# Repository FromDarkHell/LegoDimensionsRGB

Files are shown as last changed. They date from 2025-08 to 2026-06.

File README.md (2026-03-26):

## LegoDimensionsRGB

This project is a reverse-engineered implementation of a LEGO Dimensions (currently *only* PS3 / Wii U) playpad.  
This project also includes a simpler project which communicates with an OEM playpad to act as a lamp/night-light, as well as a Python script for communication as well.

### Project Layout
Inside of `projects`, you can see a few different sub-projects which each have their own purpose.

- [basic-emulator](/projects/basic-emulator/) is an implementation of the playpad HID spec, running on a Raspberry Pi Pico W, alongside a Web UI for easy controls.
- [rgb-controller](/projects/rgb-controller/) is a simpler project which sends basic USB HID commands *to* an existing, stock playpad for use as a lamp. This is powered by an ESP32-S3, and comes with a simple Web UI for controlling colors.

### Credits

A large portion of the emulator project is based on [AlinaNova21/node-ld](https://github.com/AlinaNova21/node-ld/tree/master), as well as [Berny23/LD-Toypad-Emulator](https://github.com/Berny23/LD-ToyPad-Emulator).

The Python tools is predominantly based on [woodenphone/lego_dimensions_protocol](https://github.com/woodenphone/lego_dimensions_protocol/blob/master/lego_dimensions_gateway.py). The main difference is that I have updated it to support Python 3 as well as added a `connected()` status function to determine if the playpad was disconnected.

### Support

If you for some reason want to support me financially for this project (or others I make), you can donate to me via [ko-fi](https://ko-fi.com/fromdarkhell) or [Patreon](https://patreon.com/fromdarkhell).



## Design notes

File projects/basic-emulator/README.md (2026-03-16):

# `basic-emulator`

A hardware/firmware project that emulates a LEGO Dimensions Toypad using a Raspberry Pi Pico W (or Pico 2W). It presents itself to a host console as a genuine playpad, and exposes a web interface for managing toys, placing them on the pad, etc.

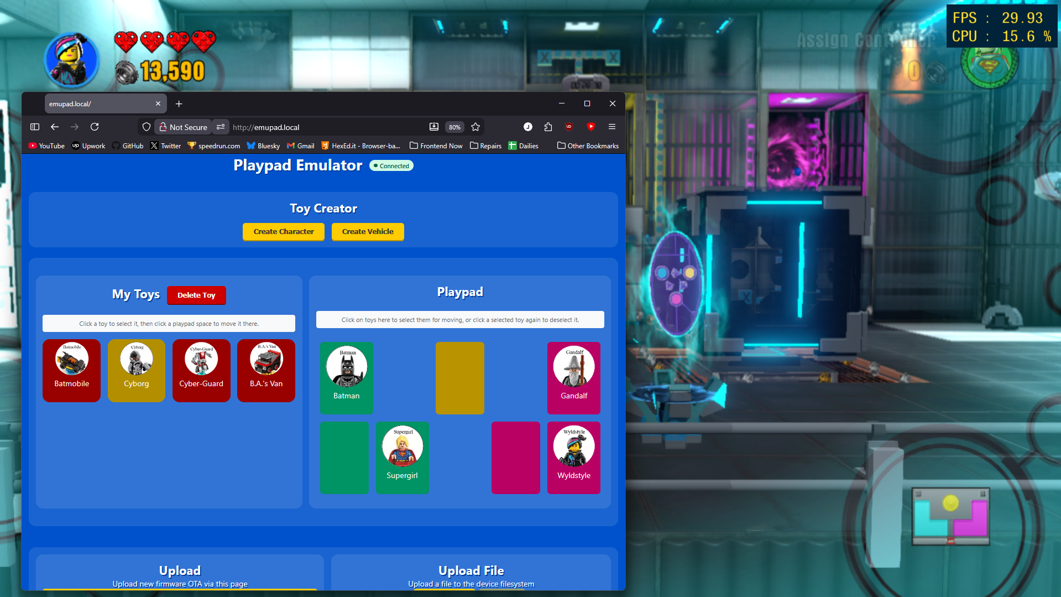
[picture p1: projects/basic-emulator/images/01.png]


---

## Firmware

The firmware lives in `firmware/` and is built with **PlatformIO**.

### Prerequisites

- [PlatformIO Core](https://docs.platformio.org/en/latest/core/installation/index.html) (CLI or IDE)
- A Raspberry Pi Pico W **or** Pico 2W
- A USB cable

### Building & Flashing

```bash
# Clone / enter the firmware directory
cd firmware

# Build for your target platform: `picow` or `pico2w`
pio run -e pico2w

# Flash (put the board in BOOTSEL mode first, then)
pio run -e picow --target upload
```

The project uses the `earlephilhower` Arduino core for RP2040/RP2350 and the `LittleFS` filesystem. Key library dependencies (resolved automatically by PlatformIO) are:

- `ESPAsyncWebServer` - async HTTP server
- `ElegantOTA` - over-the-air firmware updates
- `ArduinoJson` - JSON serialization
- `Adafruit TinyUSB Library` - USB HID stack

### Uploading the Filesystem Image

The web interface (`data/`) must be uploaded to the Pico's LittleFS partition separately:

```bash
pio run -e picow --target uploadfs
```

This packages tag images, etc into a LittleFS image and writes it to the device.

---

## First-Time Setup

On first boot (or after a factory reset), the device has no Wi-Fi credentials and enters **captive-portal mode**:

1. The LED on the board blinks 5 times rapidly to indicate portal mode.
2. A Wi-Fi access point named `captive` appears. Connect to it from your phone or computer.
3. Your device should automatically redirect to the setup page. If it doesn't, navigate to `http://192.168.4.1`.
4. Enter your Wi-Fi **SSID** (Name) and **Password**, then tap **Connect**.
5. The device saves the credentials, reboots, and connects to your network.

After a successful connection, the device should be accessible at:

```
http://emupad.local
```
---

## Using the Web Interface

The main page at `http://emupad.local` is divided into three areas: **Toy Creator**, **My Toys / Playpad**, and an **Advanced** section.

### Toy Creator

Click **Create Character** or **Create Vehicle** to open a selector modal populated from the built-in JSON databases (`json/characters.json` and `json/vehicles.json`). These contain every released LEGO Dimensions character and vehicle along with their IDs and abilities.

- For **characters**, click the character's portrait to add it to your toybox.
- For **vehicles**, expand the entry to see the base form and any rebuild variants, then click the one you want.

Each toy is assigned a random NFC UID at creation time so the game treats it as a unique physical tag.

### Playpad

The on-screen playpad mirrors the physical layout of the real LEGO Dimensions toypad:

```
[ Left  ]       [ Center ]       [ Right ]
[ Left  ][ Left ]         [ Right ][ Right ]
```

**Moving a toy onto the pad:**
1. Click a toy in the **My Toys** list - it highlights with a blue dashed border.
2. Click any empty pad space. The toy moves there and the host console is notified via a USB HID event.

**Moving a toy between pad spaces:**
1. Click a toy already on the pad to select it.
2. Click another pad space (occupied or empty). The toys swap.

**Moving a toy back to the toybox:**
- Click a selected toy on the pad a second time, or click **Delete Toy** while a toybox toy is selected to permanently remove it.

The pad color/flash/fade animations shown in the UI are driven by a **WebSocket** connection (`ws://emupad.local/ws`) that mirrors the real LED state pushed by the game.

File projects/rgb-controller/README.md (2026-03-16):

## rgb-controller

This project is a simple ESP32-S3-based controller for (PS3/Wii U/PS4) LEGO Dimensions playpads.  
Note: **This project does not emulate a full playpad. It only provides remote control of the LED colors via a web interface.**

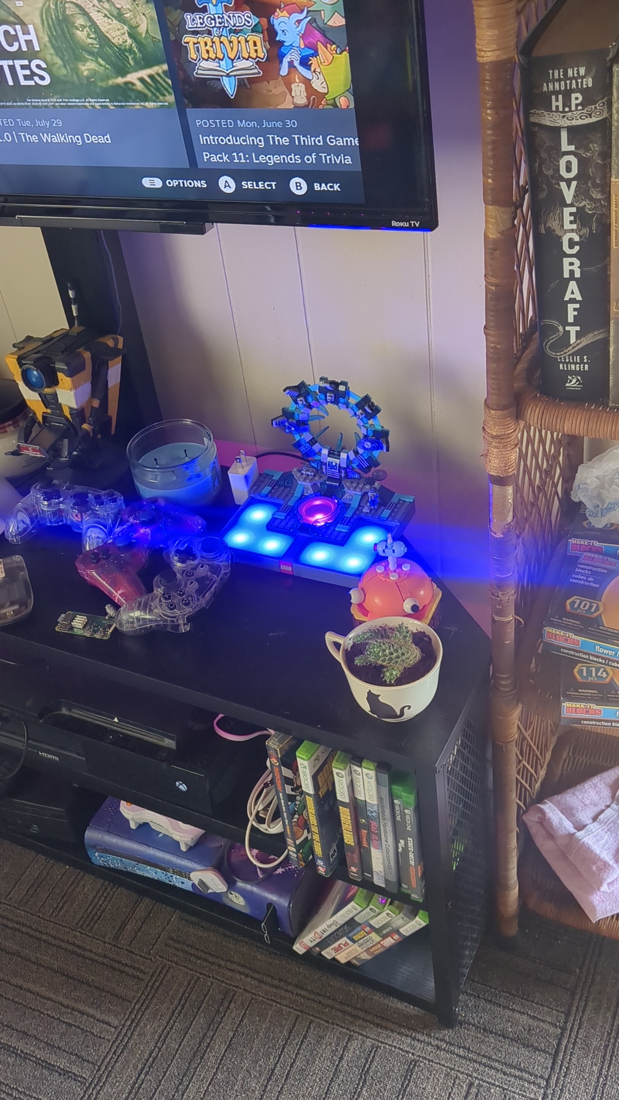
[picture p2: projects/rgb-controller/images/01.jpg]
  
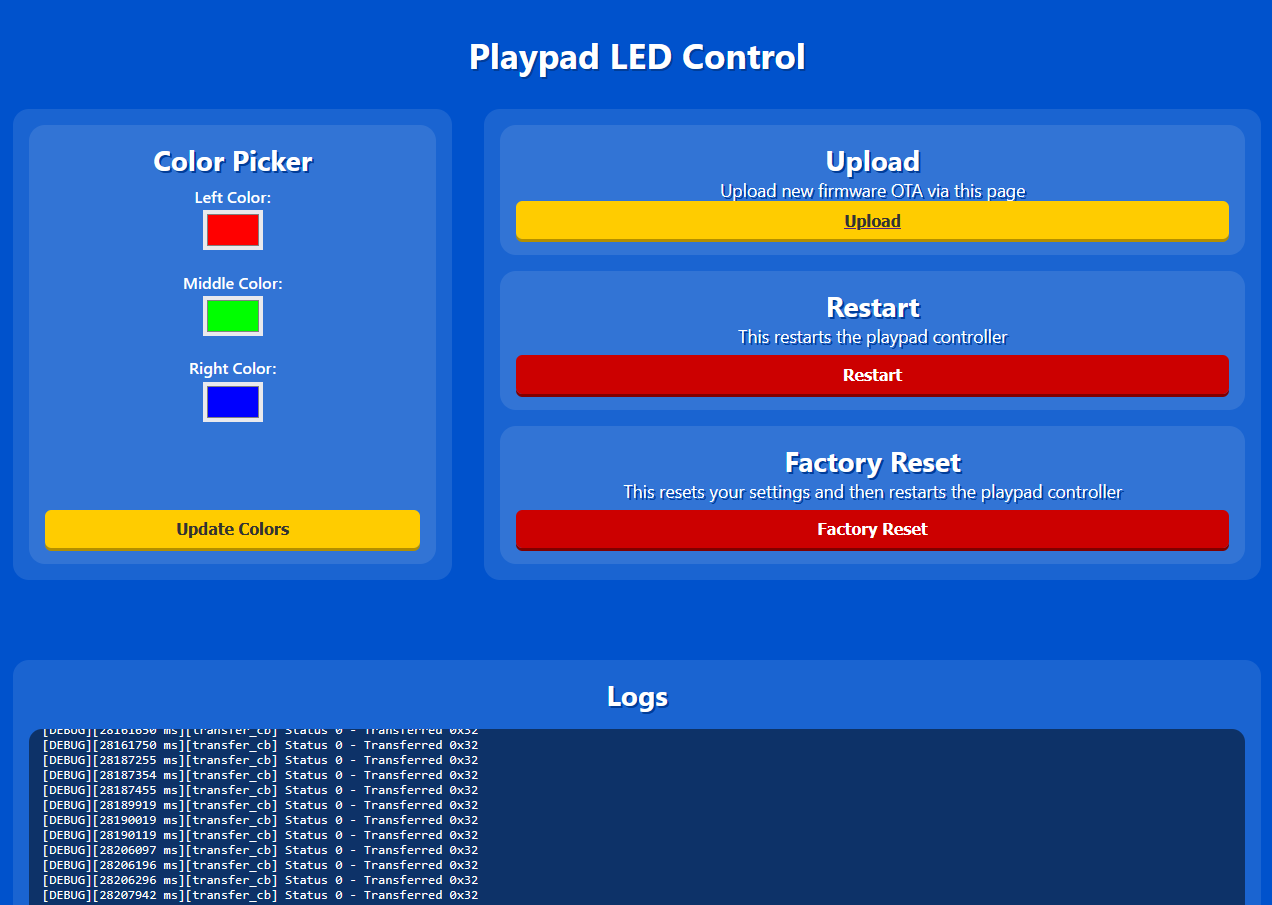
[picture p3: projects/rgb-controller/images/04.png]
  

### Features

- Control the colors via a basic HTML webpage
- (Semi) real-time HTTP logs of USB packets / etc

### Hardware
- ESP32-S3 (i.e. [Seeed Studio XIAO ESP32-S3](https://wiki.seeedstudio.com/xiao_esp32s3_getting_started/))
- USB 2.0 Breakout Board ([Example](https://www.amazon.com/dp/B07W7XMV3W))

How To:
- Connect the USB breakout board D-/D+ pins to your ESP32  
- Splice a USB cable (or use a USB C/etc breakout board), and connect the VUSB and GND to the ESP32 *and* the USB Breakout Board.  

Additionally, this repo also includes a basic schematic & PCB which you can use as a guide, or as an easy to use wiring setup. Enjoy!  

### Usage

1. Flash the firmware onto your ESP32-S3
2. Wire your ESP32-S3 (see above)
3. Connect your ESP32-S3 to your power source
4. It will create a WiFi AP you can connect to named, `captive`.
    - Connect to `captive`, and then enter your WiFi credentials.
5. Wait for the reboot, and connect to your WiFi network.
6. Then you can access the playpad via `playpad.local` (via MDNS)
7. Start changing colors!

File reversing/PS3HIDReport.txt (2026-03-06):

    =========================== USB Port20 ===========================

Connection Status        : 0x01 (Device is connected)
Port Chain               : 4-20
Properties               : 0x00
 IsUserConnectable       : no
 PortIsDebugCapable      : no
 PortHasMultiCompanions  : no
 PortConnectorIsTypeC    : no
ConnectionIndex          : 0x14 (Port 20)

      ========================== Summary =========================
Vendor ID                : 0x0E6F (Performance Designed Products, LLC)
Product ID               : 0x0241
Manufacturer String      : "PDP LIMITED. "
Product String           : "LEGO READER V2.10"
Serial                   : "P.D.P.000000"
USB Version              : 2.0 (but 12 Mbit/s FullSpeed only)
Port maximum Speed       : High-Speed
Device maximum Speed     : Full-Speed
Device Connection Speed  : Full-Speed
Self powered             : no
Demanded Current         : 500 mA
Used Endpoints           : 3

      ======================== USB Device ========================

        +++++++++++++++++ Device Information ++++++++++++++++++
Device Description       : LEGO READER V2.10
Device Path 1            : \\?\USB#VID_0E6F&PID_0241#P.D.P.000000#{a5dcbf10-6530-11d2-901f-00c04fb951ed} (GUID_DEVINTERFACE_USB_DEVICE)
Device Path 2            : \\?\USB#VID_0E6F&PID_0241#P.D.P.000000#{f9918b60-abfb-433d-b843-7d22a140b576}
Kernel Name              : \Device\USBPDO-21
Device ID                : USB\VID_0E6F&PID_0241\P.D.P.000000
Hardware IDs             : USB\VID_0E6F&PID_0241&REV_0100 USB\VID_0E6F&PID_0241
Driver KeyName           : {eb781aaf-9c70-4523-a5df-642a87eca567}\0001
Driver                   : \SystemRoot\system32\DRIVERS\libusb0.sys (Version: 1.4.0.0  Date: 2025-06-22  Company: https://github.com/mcuee/libusb-win32)
Driver Inf               : C:\WINDOWS\inf\oem47.inf
Legacy BusType           : PNPBus
Class                    : libusb-win32 devices
Class GUID               : {eb781aaf-9c70-4523-a5df-642a87eca567}
Service                  : libusb0
Enumerator               : USB
Location Info            : Port_#0020.Hub_#0001
Address                  : 20
Location IDs             : PCIROOT(0)#PCI(0103)#PCI(0000)#USBROOT(0)#USB(20), ACPI(_SB_)#ACPI(PCI0)#ACPI(GPP2)#ACPI(PTXH)#ACPI(RHUB)#ACPI(PO20)
Container ID             : {c89eb567-36c5-5252-9b41-de3970082e29}
Manufacturer Info        : Logic3
Capabilities             : 0x94 (Removable, UniqueID, SurpriseRemovalOK)
Status                   : 0x0180600A (DN_DRIVER_LOADED, DN_STARTED, DN_DISABLEABLE, DN_REMOVABLE, DN_NT_ENUMERATOR, DN_NT_DRIVER)
First Install Date       : 2026-02-15 16:47:03
Last Arrival Date        : 2026-02-15 17:16:39
EnhancedPowerMgmtEnabled : 0
Power State              : D0 (supported: D0, D3, wake from D0)

        +++++++++++++++++ Registry USB Flags +++++++++++++++++
HKEY_LOCAL_MACHINE\SYSTEM\CurrentControlSet\Control\usbflags\0E6F02410100
 osvc                    : REG_BINARY 00 00

        ---------------- Connection Information ---------------
Connection Index         : 0x14 (Port 20)
Connection Status        : 0x01 (DeviceConnected)
Current Config Value     : 0x01 (Configuration 1)
Device Address           : 0x5F (95)
Is Hub                   : 0x00 (no)
Device Bus Speed         : 0x01 (Full-Speed)
Number of open Pipes     : 0x02 (2 pipes to data endpoints)
Pipe[0]                  : EndpointID=1  Direction=IN   ScheduleOffset=0  Type=Interrupt  wMaxPacketSize=0x20    bInterval=1   -> 420 Bits/ms = 52500 Bytes/s
Pipe[1]                  : EndpointID=1  Direction=OUT  ScheduleOffset=0  Type=Interrupt  wMaxPacketSize=0x20    bInterval=1   -> 420 Bits/ms = 52500 Bytes/s
Data (HexDump)           : 14 00 00 00 12 01 00 02 00 00 00 40 6F 0E 41 02   ...........@o.A.
                           00 01 01 02 03 01 01 01 00 5F 00 02 00 00 00 01   ........._......
                           00 00 00 07 05 81 03 20 00 01 00 00 00 00 07 05   ....... ........
                           01 03 20 00 01 00 00 00 00                        .. ......

        --------------- Connection Information V2 -------------
Connection Index         : 0x14 (20)
Length                   : 0x10 (16 bytes)
SupportedUsbProtocols    : 0x03
 Usb110                  : 1 (yes, port supports USB 1.1)
 Usb200                  : 1 (yes, port supports USB 2.0)
 Usb300                  : 0 (no, port not supports USB 3.0)
 ReservedMBZ             : 0x00
Flags                    : 0x00
 DevIsOpAtSsOrHigher     : 0 (Device is not operating at SuperSpeed or higher)
 DevIsSsCapOrHigher      : 0 (Device is not SuperSpeed capable or higher)
 DevIsOpAtSsPlusOrHigher : 0 (Device is not operating at SuperSpeedPlus or higher)
 DevIsSsPlusCapOrHigher  : 0 (Device is not SuperSpeedPlus capable or higher)
 ReservedMBZ             : 0x00
Data (HexDump)           : 14 00 00 00 10 00 00 00 03 00 00 00 00 00 00 00   ................

    ---------------------- Device Descriptor ----------------------
bLength                  : 0x12 (18 bytes)
bDescriptorType          : 0x01 (Device Descriptor)
bcdUSB                   : 0x200 (USB Version 2.0) -> but device is Full-Speed only
bDeviceClass             : 0x00 (defined by the interface descriptors)
bDeviceSubClass          : 0x00
bDeviceProtocol          : 0x00
bMaxPacketSize0          : 0x40 (64 bytes)
idVendor                 : 0x0E6F (Performance Designed Products, LLC)
idProduct                : 0x0241
bcdDevice                : 0x0100
iManufacturer            : 0x01 (String Descriptor 1)
 Language 0x0409         : "PDP LIMITED. "
iProduct                 : 0x02 (String Descriptor 2)
 Language 0x0409         : "LEGO READER V2.10"
iSerialNumber            : 0x03 (String Descriptor 3)
 Language 0x0409         : "P.D.P.000000"
bNumConfigurations       : 0x01 (1 Configuration)
Data (HexDump)           : 12 01 00 02 00 00 00 40 6F 0E 41 02 00 01 01 02   .......@o.A.....
                           03 01                                             ..

    ------------------ Configuration Descriptor -------------------
bLength                  : 0x09 (9 bytes)
bDescriptorType          : 0x02 (Configuration Descriptor)
wTotalLength             : 0x0029 (41 bytes)
bNumInterfaces           : 0x01 (1 Interface)
bConfigurationValue      : 0x01 (Configuration 1)
iConfiguration           : 0x00 (No String Descriptor)
bmAttributes             : 0x80
 D7: Reserved, set 1     : 0x01
 D6: Self Powered        : 0x00 (no)
 D5: Remote Wakeup       : 0x00 (no)
 D4..0: Reserved, set 0  : 0x00
MaxPower                 : 0xFA (500 mA)
Data (HexDump)           : 09 02 29 00 01 01 00 80 FA 09 04 00 00 02 03 00   ..).............
                           00 00 09 21 00 01 00 01 22 1D 00 07 05 81 03 20   ...!...."...... 
                           00 01 07 05 01 03 20 00 01                        ...... ..

        ---------------- Interface Descriptor -----------------
bLength                  : 0x09 (9 bytes)
bDescriptorType          : 0x04 (Interface Descriptor)
bInterfaceNumber         : 0x00 (Interface 0)
bAlternateSetting        : 0x00
bNumEndpoints            : 0x02 (2 Endpoints)
bInterfaceClass          : 0x03 (HID - Human Interface Device)
bInterfaceSubClass       : 0x00 (None)
bInterfaceProtocol       : 0x00 (None)
iInterface               : 0x00 (No String Descriptor)
Data (HexDump)           : 09 04 00 00 02 03 00 00 00                        .........

        ------------------- HID Descriptor --------------------
bLength                  : 0x09 (9 bytes)
bDescriptorType          : 0x21 (HID Descriptor)
bcdHID                   : 0x0100 (HID Version 1.00)
bCountryCode             : 0x00 (00 = not localized)
bNumDescriptors          : 0x01
Data (HexDump)           : 09 21 00 01 00 01 22 1D 00                        .!...."..
Descriptor 1:
bDescriptorType          : 0x22 (Class=Report)
wDescriptorLength        : 0x001D (29 bytes)
Error reading descriptor : ERROR_GEN_FAILURE (due to a obscure limitation of the Win32 USB API, see F1 Help)

        ----------------- Endpoint Descriptor -----------------
bLength                  : 0x07 (7 bytes)
bDescriptorType          : 0x05 (Endpoint Descriptor)
bEndpointAddress         : 0x81 (Direction=IN EndpointID=1)
bmAttributes             : 0x03 (TransferType=Interrupt)
wMaxPacketSize           : 0x0020 (32 bytes)
bInterval                : 0x01 (1 ms)
Data (HexDump)           : 07 05 81 03 20 00 01                              .... ..

        ----------------- Endpoint Descriptor -----------------
bLength                  : 0x07 (7 bytes)
bDescriptorType          : 0x05 (Endpoint Descriptor)
bEndpointAddress         : 0x01 (Direction=OUT EndpointID=1)
bmAttributes             : 0x03 (TransferType=Interrupt)
wMaxPacketSize           : 0x0020 (32 bytes)
bInterval                : 0x01 (1 ms)
Data (HexDump)           : 07 05 01 03 20 00 01                              .... ..

    ----------------- Device Qualifier Descriptor -----------------
Error                    : ERROR_GEN_FAILURE  (because the device is Full-Speed only)

      -------------------- String Descriptors -------------------
             ------ String Descriptor 0 ------
bLength                  : 0x04 (4 bytes)
bDescriptorType          : 0x03 (String Descriptor)
Language ID[0]           : 0x0409 (English - United States)
Data (HexDump)           : 04 03 09 04                                       ....
             ------ String Descriptor 1 ------
bLength                  : 0x1C (28 bytes)
bDescriptorType          : 0x03 (String Descriptor)
Language 0x0409          : "PDP LIMITED. "  *!*CAUTION  trailing space character
Data (HexDump)           : 1C 03 50 00 44 00 50 00 20 00 4C 00 49 00 4D 00   ..P.D.P. .L.I.M.
                           49 00 54 00 45 00 44 00 2E 00 20 00               I.T.E.D... .
             ------ String Descriptor 2 ------
bLength                  : 0x24 (36 bytes)
bDescriptorType          : 0x03 (String Descriptor)
Language 0x0409          : "LEGO READER V2.10"
Data (HexDump)           : 24 03 4C 00 45 00 47 00 4F 00 20 00 52 00 45 00   $.L.E.G.O. .R.E.
                           41 00 44 00 45 00 52 00 20 00 56 00 32 00 2E 00   A.D.E.R. .V.2...
                           31 00 30 00                                       1.0.
             ------ String Descriptor 3 ------
bLength                  : 0x1A (26 bytes)
bDescriptorType          : 0x03 (String Descriptor)
Language 0x0409          : "P.D.P.000000"
Data (HexDump)           : 1A 03 50 00 2E 00 44 00 2E 00 50 00 2E 00 30 00   ..P...D...P...0.
                           30 00 30 00 30 00 30 00 30 00                     0.0.0.0.0.

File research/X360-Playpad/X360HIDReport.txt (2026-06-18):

    =========================== USB Port21 ===========================

Connection Status        : 0x01 (Device is connected)
Port Chain               : 4-21
Properties               : 0x00
 IsUserConnectable       : no
 PortIsDebugCapable      : no
 PortHasMultiCompanions  : no
 PortConnectorIsTypeC    : no
ConnectionIndex          : 0x15 (Port 21)

      ========================== Summary =========================
Vendor ID                : 0x24C6 (Xbox 3rd Party Partners)
Product ID               : 0xFA01
Manufacturer String      : "Warner Bros."
Product String           : "LEGO(R) DIMENSIONS(TM)"
Serial                   : "03108E28"
USB Version              : 2.0 (but 12 Mbit/s FullSpeed only)
Port maximum Speed       : High-Speed
Device maximum Speed     : Full-Speed
Device Connection Speed  : Full-Speed
Self powered             : no
Demanded Current         : 500 mA
Used Endpoints           : 8

      ======================== USB Device ========================

        +++++++++++++++++ Device Information ++++++++++++++++++
Device Description       : LEGO(R) DIMENSIONS(TM)
Device Path 1            : \\?\USB#VID_24C6&PID_FA01#03108E28#{a5dcbf10-6530-11d2-901f-00c04fb951ed} (GUID_DEVINTERFACE_USB_DEVICE)
Device Path 2            : \\?\USB#VID_24C6&PID_FA01#03108E28#{4dbbbdd3-fad6-4f9c-9e5c-694ac205453b}
Kernel Name              : \Device\USBPDO-19
Device ID                : USB\VID_24C6&PID_FA01\03108E28
Hardware IDs             : USB\VID_24C6&PID_FA01&REV_0100 USB\VID_24C6&PID_FA01
Driver KeyName           : {eb781aaf-9c70-4523-a5df-642a87eca567}\0000
Driver                   : \SystemRoot\system32\DRIVERS\libusb0.sys (Version: 1.4.0.0  Date: 2025-06-22  Company: https://github.com/mcuee/libusb-win32)
Driver Inf               : C:\WINDOWS\inf\oem92.inf
Legacy BusType           : PNPBus
Class                    : libusb-win32 devices
Class GUID               : {eb781aaf-9c70-4523-a5df-642a87eca567}
Service                  : libusb0
Enumerator               : USB
Location Info            : Port_#0021.Hub_#0001
Address                  : 21
Location IDs             : PCIROOT(0)#PCI(0103)#PCI(0000)#USBROOT(0)#USB(21), ACPI(_SB_)#ACPI(PCI0)#ACPI(GPP2)#ACPI(PTXH)#ACPI(RHUB)#ACPI(PO21)
Container ID             : {a25e410b-ebdf-58c7-9d20-ea0bfc5a89b8}
Manufacturer Info        : ThrustMaster, Inc.
Capabilities             : 0x94 (Removable, UniqueID, SurpriseRemovalOK)
Status                   : 0x0180600A (DN_DRIVER_LOADED, DN_STARTED, DN_DISABLEABLE, DN_REMOVABLE, DN_NT_ENUMERATOR, DN_NT_DRIVER)
First Install Date       : 2026-05-05 12:09:51
Last Arrival Date        : 2026-05-19 22:49:37
EnhancedPowerMgmtEnabled : 0
Power State              : D0 (supported: D0, D3, wake from D0)

        +++++++++++++++++ Registry USB Flags +++++++++++++++++
HKEY_LOCAL_MACHINE\SYSTEM\CurrentControlSet\Control\usbflags\24C6FA010100
 osvc                    : REG_BINARY 01 90
 SkipContainerIdQuery    : REG_BINARY 01 00

        ---------------- Connection Information ---------------
Connection Index         : 0x15 (Port 21)
Connection Status        : 0x01 (DeviceConnected)
Current Config Value     : 0x01 (Configuration 1)
Device Address           : 0x06 (6)
Is Hub                   : 0x00 (no)
Device Bus Speed         : 0x01 (Full-Speed)
Number of open Pipes     : 0x07 (7 pipes to data endpoints)
Pipe[0]                  : EndpointID=1  Direction=IN   ScheduleOffset=0  Type=Interrupt  wMaxPacketSize=0x20    bInterval=4   -> 420 Bits/ms = 52500 Bytes/s
Pipe[1]                  : EndpointID=1  Direction=OUT  ScheduleOffset=0  Type=Interrupt  wMaxPacketSize=0x20    bInterval=4   -> 420 Bits/ms = 52500 Bytes/s
Pipe[2]                  : EndpointID=2  Direction=IN   ScheduleOffset=0  Type=Interrupt  wMaxPacketSize=0x20    bInterval=2   -> 420 Bits/ms = 52500 Bytes/s
Pipe[3]                  : EndpointID=2  Direction=OUT  ScheduleOffset=0  Type=Interrupt  wMaxPacketSize=0x20    bInterval=4   -> 420 Bits/ms = 52500 Bytes/s
Pipe[4]                  : EndpointID=3  Direction=IN   ScheduleOffset=0  Type=Interrupt  wMaxPacketSize=0x20    bInterval=32  -> 420 Bits/ms = 52500 Bytes/s
Pipe[5]                  : EndpointID=3  Direction=OUT  ScheduleOffset=0  Type=Interrupt  wMaxPacketSize=0x20    bInterval=16  -> 420 Bits/ms = 52500 Bytes/s
Pipe[6]                  : EndpointID=4  Direction=IN   ScheduleOffset=0  Type=Interrupt  wMaxPacketSize=0x20    bInterval=16  -> 420 Bits/ms = 52500 Bytes/s
Data (HexDump)           : 15 00 00 00 12 01 00 02 FF FF FF 08 C6 24 01 FA   .............$..
                           00 01 01 02 03 01 01 01 00 06 00 07 00 00 00 01   ................
                           00 00 00 07 05 81 03 20 00 04 00 00 00 00 07 05   ....... ........
                           01 03 20 00 04 00 00 00 00 07 05 82 03 20 00 02   .. .......... ..
                           00 00 00 00 07 05 02 03 20 00 04 00 00 00 00 07   ........ .......
                           05 83 03 20 00 20 00 00 00 00 07 05 03 03 20 00   ... . ........ .
                           10 00 00 00 00 07 05 84 03 20 00 10 00 00 00 00   ......... ......

        --------------- Connection Information V2 -------------
Connection Index         : 0x15 (21)
Length                   : 0x10 (16 bytes)
SupportedUsbProtocols    : 0x03
 Usb110                  : 1 (yes, port supports USB 1.1)
 Usb200                  : 1 (yes, port supports USB 2.0)
 Usb300                  : 0 (no, port not supports USB 3.0)
 ReservedMBZ             : 0x00
Flags                    : 0x00
 DevIsOpAtSsOrHigher     : 0 (Device is not operating at SuperSpeed or higher)
 DevIsSsCapOrHigher      : 0 (Device is not SuperSpeed capable or higher)
 DevIsOpAtSsPlusOrHigher : 0 (Device is not operating at SuperSpeedPlus or higher)
 DevIsSsPlusCapOrHigher  : 0 (Device is not SuperSpeedPlus capable or higher)
 ReservedMBZ             : 0x00
Data (HexDump)           : 15 00 00 00 10 00 00 00 03 00 00 00 00 00 00 00   ................

    ---------------------- Device Descriptor ----------------------
bLength                  : 0x12 (18 bytes)
bDescriptorType          : 0x01 (Device Descriptor)
bcdUSB                   : 0x200 (USB Version 2.0) -> but device is Full-Speed only
bDeviceClass             : 0xFF (Vendor Specific)
bDeviceSubClass          : 0xFF
bDeviceProtocol          : 0xFF
bMaxPacketSize0          : 0x08 (8 bytes)
idVendor                 : 0x24C6 (Xbox 3rd Party Partners)
idProduct                : 0xFA01
bcdDevice                : 0x0100
iManufacturer            : 0x01 (String Descriptor 1)
 Language 0x0409         : "Warner Bros."
iProduct                 : 0x02 (String Descriptor 2)
 Language 0x0409         : "LEGO(R) DIMENSIONS(TM)"
iSerialNumber            : 0x03 (String Descriptor 3)
 Language 0x0409         : "03108E28"
bNumConfigurations       : 0x01 (1 Configuration)
Data (HexDump)           : 12 01 00 02 FF FF FF 08 C6 24 01 FA 00 01 01 02   .........$......
                           03 01                                             ..

    ------------------ Configuration Descriptor -------------------
bLength                  : 0x09 (9 bytes)
bDescriptorType          : 0x02 (Configuration Descriptor)
wTotalLength             : 0x0099 (153 bytes)
bNumInterfaces           : 0x04 (4 Interfaces)
bConfigurationValue      : 0x01 (Configuration 1)
iConfiguration           : 0x00 (No String Descriptor)
bmAttributes             : 0x80
 D7: Reserved, set 1     : 0x01
 D6: Self Powered        : 0x00 (no)
 D5: Remote Wakeup       : 0x00 (no)
 D4..0: Reserved, set 0  : 0x00
MaxPower                 : 0xFA (500 mA)
Data (HexDump)           : 09 02 99 00 04 01 00 80 FA 09 04 00 00 02 FF 5D   ...............]
                           01 00 11 21 10 01 21 25 81 14 00 00 00 00 13 01   ...!..!%........
                           08 00 00 07 05 81 03 20 00 04 07 05 01 03 20 00   ....... ...... .
                           04 09 04 01 00 04 FF 5D 03 00 1B 21 00 01 21 01   .......]...!..!.
                           82 20 01 02 20 16 83 00 00 00 00 00 00 16 03 00   . .. ...........
                           00 00 00 00 00 07 05 82 03 20 00 02 07 05 02 03   ......... ......
                           20 00 04 07 05 83 03 20 00 20 07 05 03 03 20 00    ...... . .... .
                           10 09 04 02 00 01 FF 5D 02 00 09 21 00 01 21 22   .......]...!..!"
                           84 07 00 07 05 84 03 20 00 10 09 04 03 00 00 FF   ....... ........
                           FD 13 04 06 41 00 01 01 03                        ....A....

        ---------------- Interface Descriptor -----------------
bLength                  : 0x09 (9 bytes)
bDescriptorType          : 0x04 (Interface Descriptor)
bInterfaceNumber         : 0x00 (Interface 0)
bAlternateSetting        : 0x00
bNumEndpoints            : 0x02 (2 Endpoints)
bInterfaceClass          : 0xFF (Vendor Specific)
bInterfaceSubClass       : 0x5D
bInterfaceProtocol       : 0x01
iInterface               : 0x00 (No String Descriptor)
Data (HexDump)           : 09 04 00 00 02 FF 5D 01 00                        ......]..

        ----------------- Unknown Descriptor ------------------
bLength                  : 0x11 (17 bytes)
bDescriptorType          : 0x21
Data (HexDump)           : 11 21 10 01 21 25 81 14 00 00 00 00 13 01 08 00 
                           00 

        ----------------- Endpoint Descriptor -----------------
bLength                  : 0x07 (7 bytes)
bDescriptorType          : 0x05 (Endpoint Descriptor)
bEndpointAddress         : 0x81 (Direction=IN EndpointID=1)
bmAttributes             : 0x03 (TransferType=Interrupt)
wMaxPacketSize           : 0x0020 (32 bytes)
bInterval                : 0x04 (4 ms)
Data (HexDump)           : 07 05 81 03 20 00 04                              .... ..

        ----------------- Endpoint Descriptor -----------------
bLength                  : 0x07 (7 bytes)
bDescriptorType          : 0x05 (Endpoint Descriptor)
bEndpointAddress         : 0x01 (Direction=OUT EndpointID=1)
bmAttributes             : 0x03 (TransferType=Interrupt)
wMaxPacketSize           : 0x0020 (32 bytes)
bInterval                : 0x04 (4 ms)
Data (HexDump)           : 07 05 01 03 20 00 04                              .... ..

        ---------------- Interface Descriptor -----------------
bLength                  : 0x09 (9 bytes)
bDescriptorType          : 0x04 (Interface Descriptor)
bInterfaceNumber         : 0x01 (Interface 1)
bAlternateSetting        : 0x00
bNumEndpoints            : 0x04 (4 Endpoints)
bInterfaceClass          : 0xFF (Vendor Specific)
bInterfaceSubClass       : 0x5D
bInterfaceProtocol       : 0x03
iInterface               : 0x00 (No String Descriptor)
Data (HexDump)           : 09 04 01 00 04 FF 5D 03 00                        ......]..

        ----------------- Unknown Descriptor ------------------
bLength                  : 0x1B (27 bytes)
bDescriptorType          : 0x21
Data (HexDump)           : 1B 21 00 01 21 01 82 20 01 02 20 16 83 00 00 00 
                           00 00 00 16 03 00 00 00 00 00 00 

        ----------------- Endpoint Descriptor -----------------
bLength                  : 0x07 (7 bytes)
bDescriptorType          : 0x05 (Endpoint Descriptor)
bEndpointAddress         : 0x82 (Direction=IN EndpointID=2)
bmAttributes             : 0x03 (TransferType=Interrupt)
wMaxPacketSize           : 0x0020 (32 bytes)
bInterval                : 0x02 (2 ms)
Data (HexDump)           : 07 05 82 03 20 00 02                              .... ..

        ----------------- Endpoint Descriptor -----------------
bLength                  : 0x07 (7 bytes)
bDescriptorType          : 0x05 (Endpoint Descriptor)
bEndpointAddress         : 0x02 (Direction=OUT EndpointID=2)
bmAttributes             : 0x03 (TransferType=Interrupt)
wMaxPacketSize           : 0x0020 (32 bytes)
bInterval                : 0x04 (4 ms)
Data (HexDump)           : 07 05 02 03 20 00 04                              .... ..

        ----------------- Endpoint Descriptor -----------------
bLength                  : 0x07 (7 bytes)
bDescriptorType          : 0x05 (Endpoint Descriptor)
bEndpointAddress         : 0x83 (Direction=IN EndpointID=3)
bmAttributes             : 0x03 (TransferType=Interrupt)
wMaxPacketSize           : 0x0020 (32 bytes)
bInterval                : 0x20 (32 ms)
Data (HexDump)           : 07 05 83 03 20 00 20                              .... . 

        ----------------- Endpoint Descriptor -----------------
bLength                  : 0x07 (7 bytes)
bDescriptorType          : 0x05 (Endpoint Descriptor)
bEndpointAddress         : 0x03 (Direction=OUT EndpointID=3)
bmAttributes             : 0x03 (TransferType=Interrupt)
wMaxPacketSize           : 0x0020 (32 bytes)
bInterval                : 0x10 (16 ms)
Data (HexDump)           : 07 05 03 03 20 00 10                              .... ..

        ---------------- Interface Descriptor -----------------
bLength                  : 0x09 (9 bytes)
bDescriptorType          : 0x04 (Interface Descriptor)
bInterfaceNumber         : 0x02 (Interface 2)
bAlternateSetting        : 0x00
bNumEndpoints            : 0x01 (1 Endpoint)
bInterfaceClass          : 0xFF (Vendor Specific)
bInterfaceSubClass       : 0x5D
bInterfaceProtocol       : 0x02
iInterface               : 0x00 (No String Descriptor)
Data (HexDump)           : 09 04 02 00 01 FF 5D 02 00                        ......]..

        ----------------- Unknown Descriptor ------------------
bLength                  : 0x09 (9 bytes)
bDescriptorType          : 0x21
Data (HexDump)           : 09 21 00 01 21 22 84 07 00 

        ----------------- Endpoint Descriptor -----------------
bLength                  : 0x07 (7 bytes)
bDescriptorType          : 0x05 (Endpoint Descriptor)
bEndpointAddress         : 0x84 (Direction=IN EndpointID=4)
bmAttributes             : 0x03 (TransferType=Interrupt)
wMaxPacketSize           : 0x0020 (32 bytes)
bInterval                : 0x10 (16 ms)
Data (HexDump)           : 07 05 84 03 20 00 10                              .... ..

        ---------------- Interface Descriptor -----------------
bLength                  : 0x09 (9 bytes)
bDescriptorType          : 0x04 (Interface Descriptor)
bInterfaceNumber         : 0x03 (Interface 3)
bAlternateSetting        : 0x00
bNumEndpoints            : 0x00 (Default Control Pipe only)
bInterfaceClass          : 0xFF (Vendor Specific)
bInterfaceSubClass       : 0xFD
bInterfaceProtocol       : 0x13
iInterface               : 0x04 (String Descriptor 4)
 Language 0x0409         : "Xbox Security Method 3, Version 1.00, © 2005 Microsoft Corporation. All rights reserved."
Data (HexDump)           : 09 04 03 00 00 FF FD 13 04                        .........

        ----------------- Unknown Descriptor ------------------
bLength                  : 0x06 (6 bytes)
bDescriptorType          : 0x41
Data (HexDump)           : 06 41 00 01 01 03 

    ----------------- Device Qualifier Descriptor -----------------
Error                    : ERROR_GEN_FAILURE  (because the device is Full-Speed only)

      -------------------- String Descriptors -------------------
             ------ String Descriptor 0 ------
bLength                  : 0x04 (4 bytes)
bDescriptorType          : 0x03 (String Descriptor)
Language ID[0]           : 0x0409 (English - United States)
Data (HexDump)           : 04 03 09 04                                       ....
             ------ String Descriptor 1 ------
bLength                  : 0x1A (26 bytes)
bDescriptorType          : 0x03 (String Descriptor)
Language 0x0409          : "Warner Bros."
Data (HexDump)           : 1A 03 57 00 61 00 72 00 6E 00 65 00 72 00 20 00   ..W.a.r.n.e.r. .
                           42 00 72 00 6F 00 73 00 2E 00                     B.r.o.s...
             ------ String Descriptor 2 ------
bLength                  : 0x2E (46 bytes)
bDescriptorType          : 0x03 (String Descriptor)
Language 0x0409          : "LEGO(R) DIMENSIONS(TM)"
Data (HexDump)           : 2E 03 4C 00 45 00 47 00 4F 00 28 00 52 00 29 00   ..L.E.G.O.(.R.).
                           20 00 44 00 49 00 4D 00 45 00 4E 00 53 00 49 00    .D.I.M.E.N.S.I.
                           4F 00 4E 00 53 00 28 00 54 00 4D 00 29 00         O.N.S.(.T.M.).
             ------ String Descriptor 3 ------
bLength                  : 0x12 (18 bytes)
bDescriptorType          : 0x03 (String Descriptor)
Language 0x0409          : "03108E28"
Data (HexDump)           : 12 03 30 00 33 00 31 00 30 00 38 00 45 00 32 00   ..0.3.1.0.8.E.2.
                           38 00                                             8.
             ------ String Descriptor 4 ------
bLength                  : 0xB2 (178 bytes)
bDescriptorType          : 0x03 (String Descriptor)
Language 0x0409          : "Xbox Security Method 3, Version 1.00, © 2005 Microsoft Corporation. All rights reserved."
Data (HexDump)           : B2 03 58 00 62 00 6F 00 78 00 20 00 53 00 65 00   ..X.b.o.x. .S.e.
                           63 00 75 00 72 00 69 00 74 00 79 00 20 00 4D 00   c.u.r.i.t.y. .M.
                           65 00 74 00 68 00 6F 00 64 00 20 00 33 00 2C 00   e.t.h.o.d. .3.,.
                           20 00 56 00 65 00 72 00 73 00 69 00 6F 00 6E 00    .V.e.r.s.i.o.n.
                           20 00 31 00 2E 00 30 00 30 00 2C 00 20 00 A9 00    .1...0.0.,. ...
                           20 00 32 00 30 00 30 00 35 00 20 00 4D 00 69 00    .2.0.0.5. .M.i.
                           63 00 72 00 6F 00 73 00 6F 00 66 00 74 00 20 00   c.r.o.s.o.f.t. .
                           43 00 6F 00 72 00 70 00 6F 00 72 00 61 00 74 00   C.o.r.p.o.r.a.t.
                           69 00 6F 00 6E 00 2E 00 20 00 41 00 6C 00 6C 00   i.o.n... .A.l.l.
                           20 00 72 00 69 00 67 00 68 00 74 00 73 00 20 00    .r.i.g.h.t.s. .
                           72 00 65 00 73 00 65 00 72 00 76 00 65 00 64 00   r.e.s.e.r.v.e.d.
                           2E 00                                             ..

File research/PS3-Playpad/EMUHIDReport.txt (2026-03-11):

    =========================== USB Port21 ===========================

Connection Status        : 0x01 (Device is connected)
Port Chain               : 4-21
Properties               : 0x00
 IsUserConnectable       : no
 PortIsDebugCapable      : no
 PortHasMultiCompanions  : no
 PortConnectorIsTypeC    : no
ConnectionIndex          : 0x15 (Port 21)

      ========================== Summary =========================
Vendor ID                : 0x0E6F (Performance Designed Products, LLC)
Product ID               : 0x0241
Manufacturer String      : "PDP LIMITED. "
Product String           : "LEGO READER V2.10"
Serial                   : "P.D.P.000000"
USB Version              : 2.0 (but 12 Mbit/s FullSpeed only)
Port maximum Speed       : High-Speed
Device maximum Speed     : Full-Speed
Device Connection Speed  : Full-Speed
Self powered             : no
Demanded Current         : 500 mA
Used Endpoints           : 3

      ======================== USB Device ========================

        +++++++++++++++++ Device Information ++++++++++++++++++
Device Description       : LEGO READER V2.10
Device Path 1            : \\?\USB#VID_0E6F&PID_0241#P.D.P.000000#{a5dcbf10-6530-11d2-901f-00c04fb951ed} (GUID_DEVINTERFACE_USB_DEVICE)
Device Path 2            : \\?\USB#VID_0E6F&PID_0241#P.D.P.000000#{483c5f02-e6d9-4d0c-971b-a141afcac42d}
Kernel Name              : \Device\USBPDO-20
Device ID                : USB\VID_0E6F&PID_0241\P.D.P.000000
Hardware IDs             : USB\VID_0E6F&PID_0241&REV_0100 USB\VID_0E6F&PID_0241
Driver KeyName           : {eb781aaf-9c70-4523-a5df-642a87eca567}\0001
Driver                   : \SystemRoot\system32\DRIVERS\libusb0.sys (Version: 1.4.0.0  Date: 2025-06-22  Company: https://github.com/mcuee/libusb-win32)
Driver Inf               : C:\WINDOWS\inf\oem25.inf
Legacy BusType           : PNPBus
Class                    : libusb-win32 devices
Class GUID               : {eb781aaf-9c70-4523-a5df-642a87eca567}
Service                  : libusb0
Enumerator               : USB
Location Info            : Port_#0021.Hub_#0001
Address                  : 21
Location IDs             : PCIROOT(0)#PCI(0103)#PCI(0000)#USBROOT(0)#USB(21), ACPI(_SB_)#ACPI(PCI0)#ACPI(GPP2)#ACPI(PTXH)#ACPI(RHUB)#ACPI(PO21)
Container ID             : {c89eb567-36c5-5252-9b41-de3970082e29}
Manufacturer Info        : Logic3
Capabilities             : 0x94 (Removable, UniqueID, SurpriseRemovalOK)
Status                   : 0x0180600A (DN_DRIVER_LOADED, DN_STARTED, DN_DISABLEABLE, DN_REMOVABLE, DN_NT_ENUMERATOR, DN_NT_DRIVER)
First Install Date       : 2026-02-15 16:47:03
Last Arrival Date        : 2026-03-10 01:25:07
EnhancedPowerMgmtEnabled : 0
Power State              : D0 (supported: D0, D1, D2, D3, wake from D0, wake from D1, wake from D2)

        +++++++++++++++++ Registry USB Flags +++++++++++++++++
HKEY_LOCAL_MACHINE\SYSTEM\CurrentControlSet\Control\usbflags\0E6F02410100
 osvc                    : REG_BINARY 00 00

        ---------------- Connection Information ---------------
Connection Index         : 0x15 (Port 21)
Connection Status        : 0x01 (DeviceConnected)
Current Config Value     : 0x01 (Configuration 1)
Device Address           : 0x46 (70)
Is Hub                   : 0x00 (no)
Device Bus Speed         : 0x01 (Full-Speed)
Number of open Pipes     : 0x02 (2 pipes to data endpoints)
Pipe[0]                  : EndpointID=1  Direction=IN   ScheduleOffset=0  Type=Interrupt  wMaxPacketSize=0x20    bInterval=1   -> 420 Bits/ms = 52500 Bytes/s
Pipe[1]                  : EndpointID=1  Direction=OUT  ScheduleOffset=0  Type=Interrupt  wMaxPacketSize=0x20    bInterval=1   -> 420 Bits/ms = 52500 Bytes/s
Data (HexDump)           : 15 00 00 00 12 01 00 02 00 00 00 40 6F 0E 41 02   ...........@o.A.
                           00 01 01 02 03 01 01 01 00 46 00 02 00 00 00 01   .........F......
                           00 00 00 07 05 81 03 20 00 01 00 00 00 00 07 05   ....... ........
                           01 03 20 00 01 00 00 00 00                        .. ......

        --------------- Connection Information V2 -------------
Connection Index         : 0x15 (21)
Length                   : 0x10 (16 bytes)
SupportedUsbProtocols    : 0x03
 Usb110                  : 1 (yes, port supports USB 1.1)
 Usb200                  : 1 (yes, port supports USB 2.0)
 Usb300                  : 0 (no, port not supports USB 3.0)
 ReservedMBZ             : 0x00
Flags                    : 0x00
 DevIsOpAtSsOrHigher     : 0 (Device is not operating at SuperSpeed or higher)
 DevIsSsCapOrHigher      : 0 (Device is not SuperSpeed capable or higher)
 DevIsOpAtSsPlusOrHigher : 0 (Device is not operating at SuperSpeedPlus or higher)
 DevIsSsPlusCapOrHigher  : 0 (Device is not SuperSpeedPlus capable or higher)
 ReservedMBZ             : 0x00
Data (HexDump)           : 15 00 00 00 10 00 00 00 03 00 00 00 00 00 00 00   ................

    ---------------------- Device Descriptor ----------------------
bLength                  : 0x12 (18 bytes)
bDescriptorType          : 0x01 (Device Descriptor)
bcdUSB                   : 0x200 (USB Version 2.0) -> but device is Full-Speed only
bDeviceClass             : 0x00 (defined by the interface descriptors)
bDeviceSubClass          : 0x00
bDeviceProtocol          : 0x00
bMaxPacketSize0          : 0x40 (64 bytes)
idVendor                 : 0x0E6F (Performance Designed Products, LLC)
idProduct                : 0x0241
bcdDevice                : 0x0100
iManufacturer            : 0x01 (String Descriptor 1)
 Language 0x0409         : "PDP LIMITED. "
iProduct                 : 0x02 (String Descriptor 2)
 Language 0x0409         : "LEGO READER V2.10"
iSerialNumber            : 0x03 (String Descriptor 3)
 Language 0x0409         : "P.D.P.000000"
bNumConfigurations       : 0x01 (1 Configuration)
Data (HexDump)           : 12 01 00 02 00 00 00 40 6F 0E 41 02 00 01 01 02   .......@o.A.....
                           03 01                                             ..

    ------------------ Configuration Descriptor -------------------
bLength                  : 0x09 (9 bytes)
bDescriptorType          : 0x02 (Configuration Descriptor)
wTotalLength             : 0x0029 (41 bytes)
bNumInterfaces           : 0x01 (1 Interface)
bConfigurationValue      : 0x01 (Configuration 1)
iConfiguration           : 0x00 (No String Descriptor)
bmAttributes             : 0xA0
 D7: Reserved, set 1     : 0x01
 D6: Self Powered        : 0x00 (no)
 D5: Remote Wakeup       : 0x01 (yes)
 D4..0: Reserved, set 0  : 0x00
MaxPower                 : 0xFA (500 mA)
Data (HexDump)           : 09 02 29 00 01 01 00 A0 FA 09 04 00 00 02 03 00   ..).............
                           00 00 09 21 11 01 00 01 22 1D 00 07 05 81 03 20   ...!...."...... 
                           00 01 07 05 01 03 20 00 01                        ...... ..

        ---------------- Interface Descriptor -----------------
bLength                  : 0x09 (9 bytes)
bDescriptorType          : 0x04 (Interface Descriptor)
bInterfaceNumber         : 0x00 (Interface 0)
bAlternateSetting        : 0x00
bNumEndpoints            : 0x02 (2 Endpoints)
bInterfaceClass          : 0x03 (HID - Human Interface Device)
bInterfaceSubClass       : 0x00 (None)
bInterfaceProtocol       : 0x00 (None)
iInterface               : 0x00 (No String Descriptor)
Data (HexDump)           : 09 04 00 00 02 03 00 00 00                        .........

        ------------------- HID Descriptor --------------------
bLength                  : 0x09 (9 bytes)
bDescriptorType          : 0x21 (HID Descriptor)
bcdHID                   : 0x0111 (HID Version 1.11)
bCountryCode             : 0x00 (00 = not localized)
bNumDescriptors          : 0x01
Data (HexDump)           : 09 21 11 01 00 01 22 1D 00                        .!...."..
Descriptor 1:
bDescriptorType          : 0x22 (Class=Report)
wDescriptorLength        : 0x001D (29 bytes)
Error reading descriptor : ERROR_GEN_FAILURE (due to a obscure limitation of the Win32 USB API, see F1 Help)

        ----------------- Endpoint Descriptor -----------------
bLength                  : 0x07 (7 bytes)
bDescriptorType          : 0x05 (Endpoint Descriptor)
bEndpointAddress         : 0x81 (Direction=IN EndpointID=1)
bmAttributes             : 0x03 (TransferType=Interrupt)
wMaxPacketSize           : 0x0020 (32 bytes)
bInterval                : 0x01 (1 ms)
Data (HexDump)           : 07 05 81 03 20 00 01                              .... ..

        ----------------- Endpoint Descriptor -----------------
bLength                  : 0x07 (7 bytes)
bDescriptorType          : 0x05 (Endpoint Descriptor)
bEndpointAddress         : 0x01 (Direction=OUT EndpointID=1)
bmAttributes             : 0x03 (TransferType=Interrupt)
wMaxPacketSize           : 0x0020 (32 bytes)
bInterval                : 0x01 (1 ms)
Data (HexDump)           : 07 05 01 03 20 00 01                              .... ..

    ----------------- Device Qualifier Descriptor -----------------
Error                    : ERROR_GEN_FAILURE  (because the device is Full-Speed only)

      ---------- Binary Object Store (BOS) Descriptor -----------
bLength                  : 0x05 (5 bytes)
bDescriptorType          : 0x0F (Binary Object Store)
wTotalLength             : 0x0039 (57 bytes)
bNumDeviceCaps           : 0x02
Data (HexDump)           : 05 0F 39 00 02                                    ..9..

        ----------- Platform Capabilities Descriptor -----------
bLength                  : 0x18 (24 bytes)
bDescriptorType          : 0x10 (Device Capability Descriptor)
bDevCapabilityType       : 0x05 (Platform Capabilities)
bReserved                : 0x00
PlatformCapabilityUUID   : 3408B638-09A9-47A0-8BFD-A0768815B665
CapabililityData         : 0
Data (HexDump)           : 18 10 05 00 38 B6 08 34 A9 09 A0 47 8B FD A0 76   ....8..4...G...v
                           88 15 B6 65 00 01 01 01                           ...e....

        ----------- Platform Capabilities Descriptor -----------
bLength                  : 0x1C (28 bytes)
bDescriptorType          : 0x10 (Device Capability Descriptor)
bDevCapabilityType       : 0x05 (Platform Capabilities)
bReserved                : 0x00
PlatformCapabilityUUID   : D8DD60DF-4589-4CC7-9CD2-659D9E648A9F (GUID_USB_MSOS20_PLATFORM_CAPABILITY_ID)
dwWindowsVersion         : 0x06030000 (Windows V6.3 and higher)
wMSOSDescSetTotalLength  : 0x00B2 (178 Bytes)
bMS_VendorCode           : 0x02 (2)
bAltEnumCode             : 0x00 (0)
Data (HexDump)           : 1C 10 05 00 DF 60 DD D8 89 45 C7 4C 9C D2 65 9D   .....`...E.L..e.
                           9E 64 8A 9F 00 00 03 06 B2 00 02 00               .d..........

      -------------------- String Descriptors -------------------
             ------ String Descriptor 0 ------
bLength                  : 0x04 (4 bytes)
bDescriptorType          : 0x03 (String Descriptor)
Language ID[0]           : 0x0409 (English - United States)
Data (HexDump)           : 04 03 09 04                                       ....
             ------ String Descriptor 1 ------
bLength                  : 0x1C (28 bytes)
bDescriptorType          : 0x03 (String Descriptor)
Language 0x0409          : "PDP LIMITED. "  *!*CAUTION  trailing space character
Data (HexDump)           : 1C 03 50 00 44 00 50 00 20 00 4C 00 49 00 4D 00   ..P.D.P. .L.I.M.
                           49 00 54 00 45 00 44 00 2E 00 20 00               I.T.E.D... .
             ------ String Descriptor 2 ------
bLength                  : 0x24 (36 bytes)
bDescriptorType          : 0x03 (String Descriptor)
Language 0x0409          : "LEGO READER V2.10"
Data (HexDump)           : 24 03 4C 00 45 00 47 00 4F 00 20 00 52 00 45 00   $.L.E.G.O. .R.E.
                           41 00 44 00 45 00 52 00 20 00 56 00 32 00 2E 00   A.D.E.R. .V.2...
                           31 00 30 00                                       1.0.
             ------ String Descriptor 3 ------
bLength                  : 0x1A (26 bytes)
bDescriptorType          : 0x03 (String Descriptor)
Language 0x0409          : "P.D.P.000000"
Data (HexDump)           : 1A 03 50 00 2E 00 44 00 2E 00 50 00 2E 00 30 00   ..P...D...P...0.
                           30 00 30 00 30 00 30 00 30 00                     0.0.0.0.0.

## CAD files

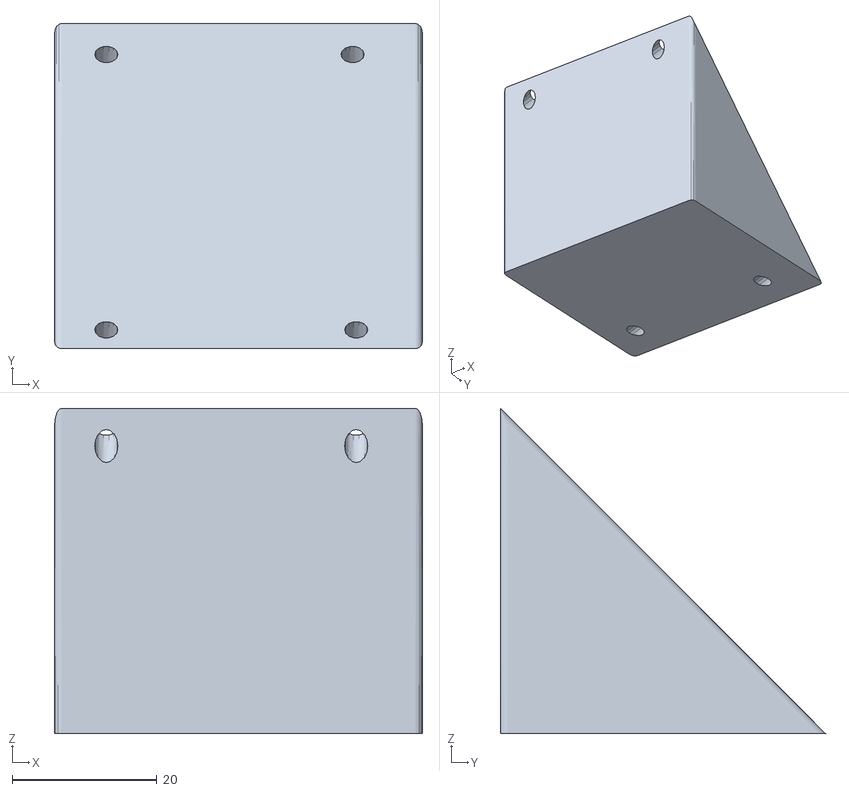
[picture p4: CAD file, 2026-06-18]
projects/basic-emulator/case/bottom-case.stl
50.8 x 44.9 x 44.9

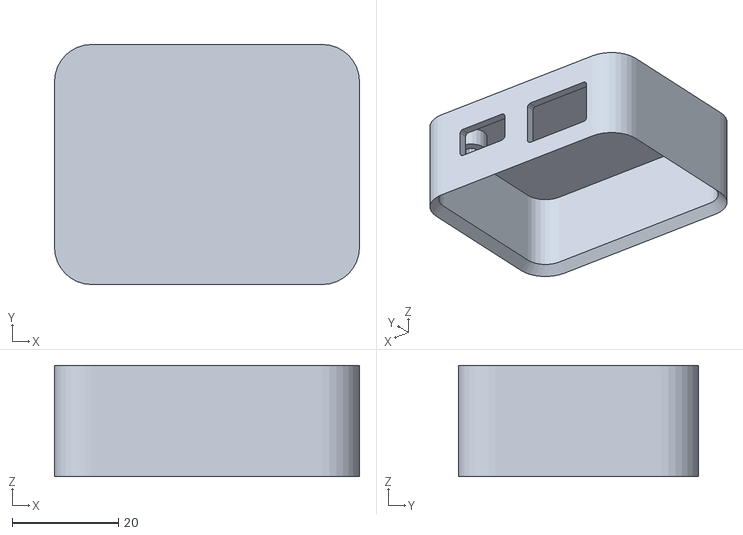
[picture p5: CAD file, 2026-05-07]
projects/rgb-controller/case/BottomShell.stl
57.5 x 45.2 x 21.0

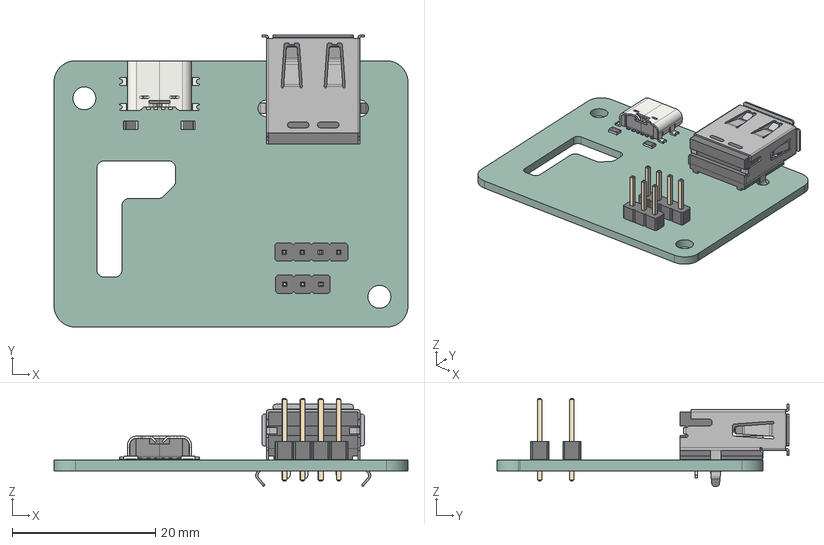
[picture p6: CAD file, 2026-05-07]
projects/rgb-controller/schematic/board-view.step
49.5 x 40.9 x 12.3 mm
PinHeader_1x03_P2.54mm_Vertical
USB_C_Receptacle_GCT_USB4135-GF-A_6P_TopMnt_Horizontal
R_0805_2012Metric x 2
USB_A_Molex_67643_Horizontal
PinHeader_1x04_P2.54mm_Vertical
basic-rgb_PCB

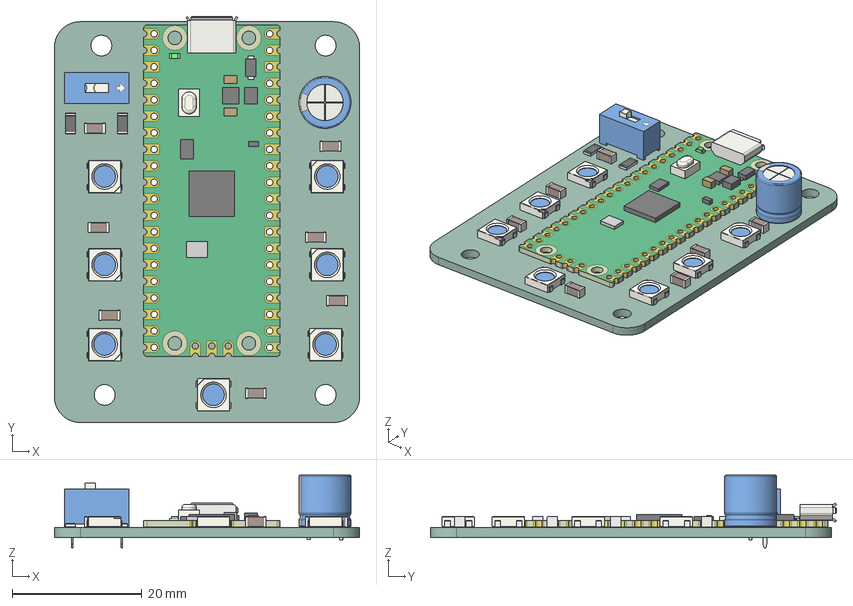
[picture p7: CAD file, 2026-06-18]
projects/basic-emulator/case/board-view.step
47.0 x 62.5 x 11.2 mm
C_1206_3216Metric x 7
LED_WS2812B_PLCC4_5.0x5.0mm_P3.2mm x 7
SW_DIP_SPSTx01_Slide_9.78x4.72mm_W7.62mm_P2.54mm
RaspberryPi_Pico_Module_KiCad
CP_Radial_D8.0mm_P5.00mm
R_1206_3216Metric x 2
basic-emulator_PCB

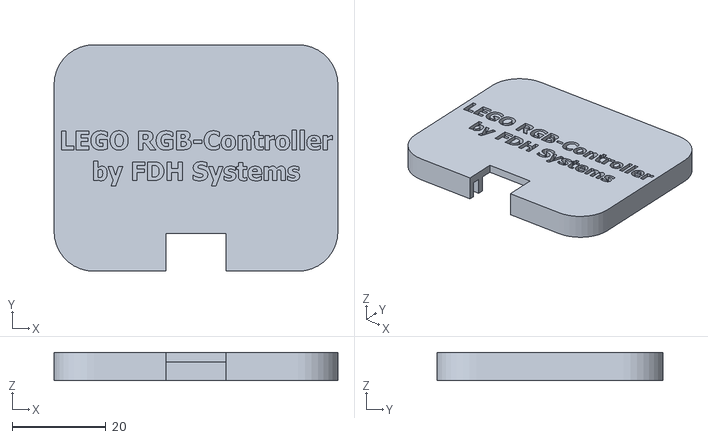
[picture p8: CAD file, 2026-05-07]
projects/rgb-controller/case/TopShell.stl
60.5 x 48.2 x 6.00

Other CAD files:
projects/basic-emulator/case/Part16.ipt
projects/basic-emulator/case/board-view/pegboardpeg.ipt
projects/basic-emulator/case/case-assembly.iam
projects/basic-emulator/case/case-top.ipt
projects/rgb-controller/case/BottomShell.ipt
projects/rgb-controller/case/TopShell.ipt
projects/rgb-controller/case/rgb-controller-case.iam

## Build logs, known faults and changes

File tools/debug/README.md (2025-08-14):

## Scripts

These are some simple little scripts which uses PyUSB (libusb) to control the colors of a Lego Dimensions RGB Pad (**Note**: only tested is PS3/Wii/Wii U gamepads).

### Installation

#### Windows
- You can install the python dependencies via `python -m pip install -r requirements.txt`
- In order to properly utilize the device via USB, you will need to install a new/different Windows driver for the Dimensions RGB Pad.
    * You can do this via [Zadig](https://zadig.akeo.ie/#), an easy USB driver installer
    * You will also need to install [libusb](https://libusb.info/)

### Usage

Once you've installed everything, you can run `python ./test.py` which will run through all of the valid color-changing functions.
If you know that it works, you can then run `python ./static-color.py --color "#FF00FF"` which will change the RGB color of the playpad. This script should always be runnin

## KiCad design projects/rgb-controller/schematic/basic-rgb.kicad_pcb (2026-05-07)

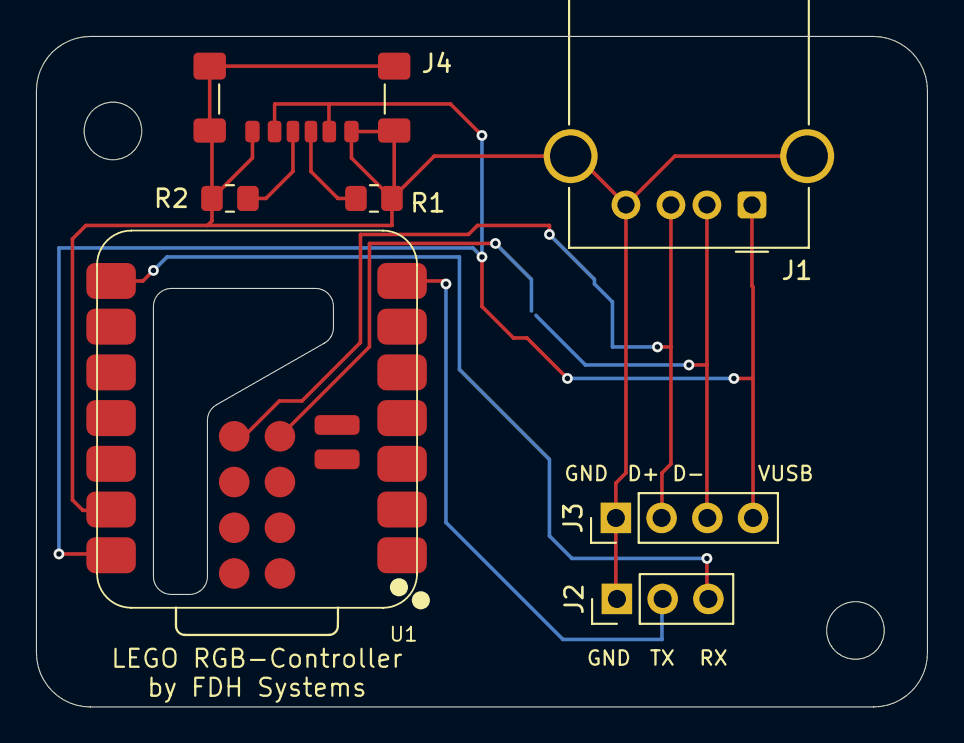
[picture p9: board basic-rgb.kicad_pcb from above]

Board: 2 copper layers, 49.5 x 37.2 mm, 7 parts (0 on the bottom side), 8 nets.

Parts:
J1: PLAYPAD; USB_A_Molex_67643_Horizontal
J2: FTDI; PinHeader_1x03_P2.54mm_Vertical
J3: USB_DBG; PinHeader_1x04_P2.54mm_Vertical
J4: USB_C_Receptacle_PowerOnly_6P; USB_C_Receptacle_GCT_USB4135-GF-A_6P_TopMnt_Horizontal
R1, R2: 5.1k; R_0805_2012Metric_Pad1.20x1.40mm_HandSolder
U1: XIAO-ESP32-S3-SMD; XIAO-ESP32S3-SMD

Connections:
+5V: J1.1 (VBUS), J3.4, J4.A9 (VBUS), J4.B9 (VBUS), U1.14 (5V)
GND: J1.4 (GND), J1.SH, J2.1, J3.1, J4.A12 (GND), J4.B12 (GND), J4.SH, R1.2, R2.2, U1.13 (GND)
unnamed: J1.3 (D+), J3.2, U1.24 (USB_DP)
unnamed: J1.2 (D-), J3.3, U1.23 (USB_DN)
unnamed: J2.2, U1.7 (GPIO43_A6_D6_TX)
unnamed: J2.3, U1.8 (GPIO44_D7_RX)
unnamed: J4.A5 (CC1), R1.1
unnamed: J4.B5 (CC2), R2.1

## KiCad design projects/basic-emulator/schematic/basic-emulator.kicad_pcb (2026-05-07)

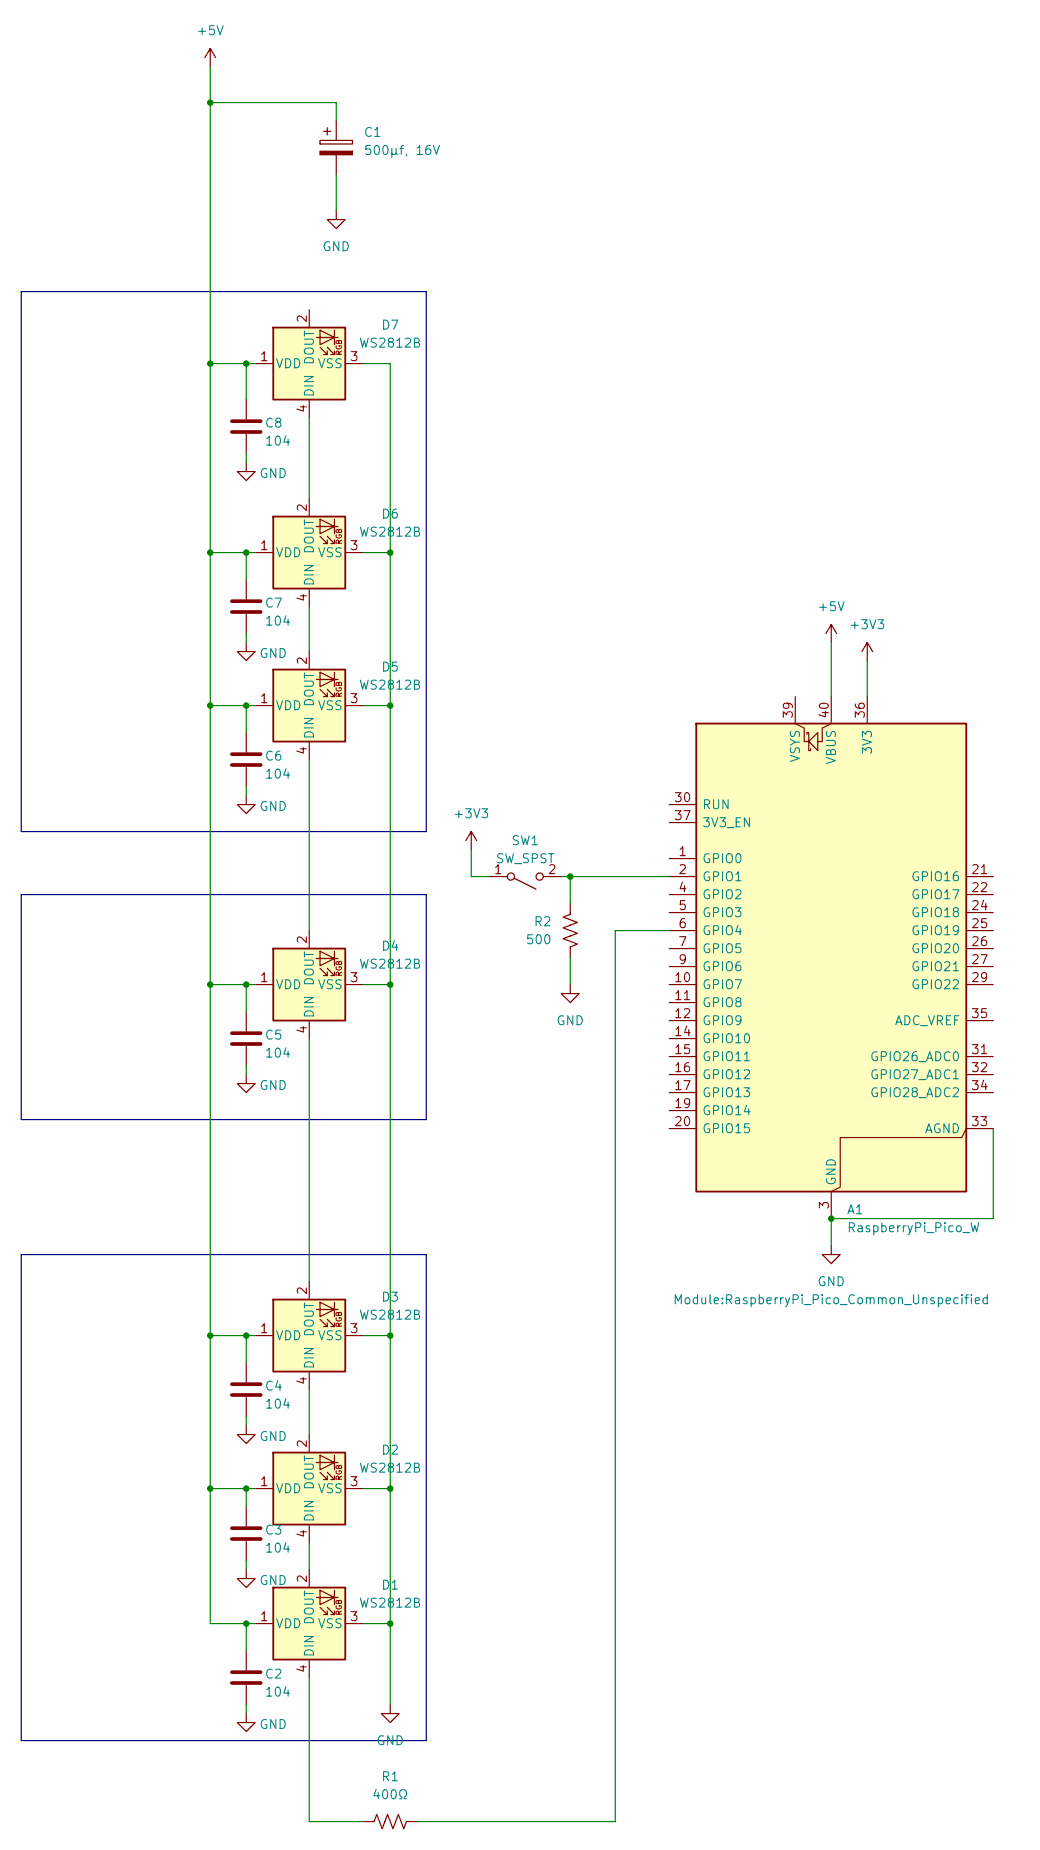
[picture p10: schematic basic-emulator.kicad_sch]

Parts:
A1: RaspberryPi_Pico_W; RaspberryPi_Pico_Common_Unspecified
C1: 500µf, 16V; CP_Radial_D8.0mm_P5.00mm
C2, C3, C4, C5, C6, C7, C8: 104; C_1206_3216Metric_Pad1.33x1.80mm_HandSolder
D1, D2, D3, D4, D5, D6, D7: WS2812B; LED_WS2812B_PLCC4_5.0x5.0mm_P3.2mm
R1: 400Ω; R_1206_3216Metric_Pad1.30x1.75mm_HandSolder
R2: 500; R_1206_3216Metric_Pad1.30x1.75mm_HandSolder
SW1: SW_SPST; SW_DIP_SPSTx01_Slide_9.78x4.72mm_W7.62mm_P2.54mm

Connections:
+3V3: A1.36 (3V3), SW1.1 (A)
+5V: A1.40 (VBUS), C1.1, C2.1, C3.1, C4.1, C5.1, C6.1, C7.1, C8.1, D1.1 (VDD), D2.1 (VDD), D3.1 (VDD), D4.1 (VDD), D5.1 (VDD), D6.1 (VDD), D7.1 (VDD)
GND: A1.3 (GND), A1.8 (GND), A1.13 (GND), A1.18 (GND), A1.23 (GND), A1.28 (GND), A1.33 (AGND), A1.38 (GND), C1.2, C2.2, C3.2, C4.2, C5.2, C6.2, C7.2, C8.2, D1.3 (VSS), D2.3 (VSS), D3.3 (VSS), D4.3 (VSS), D5.3 (VSS), D6.3 (VSS), D7.3 (VSS), R2.2
unnamed: A1.2 (GPIO1), R2.1, SW1.2 (B)
unnamed: A1.6 (GPIO4), R1.2
unnamed: D1.4 (DIN), R1.1
unnamed: D1.2 (DOUT), D2.4 (DIN)
unnamed: D2.2 (DOUT), D3.4 (DIN)
unnamed: D3.2 (DOUT), D4.4 (DIN)
unnamed: D4.2 (DOUT), D5.4 (DIN)
unnamed: D5.2 (DOUT), D6.4 (DIN)
unnamed: D6.2 (DOUT), D7.4 (DIN)

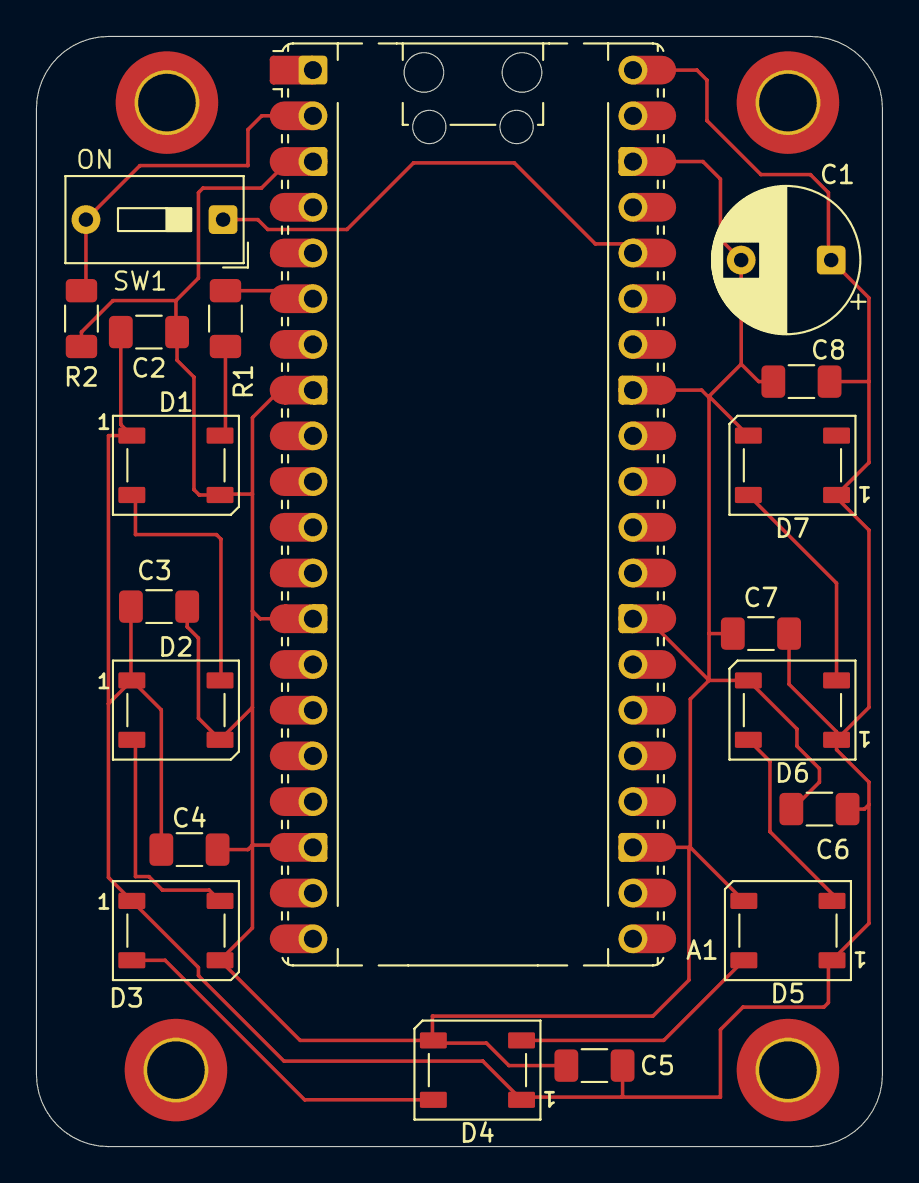
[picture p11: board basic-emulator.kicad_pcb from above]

Board: 2 copper layers, 47.0 x 61.7 mm, 19 parts (0 on the bottom side), 12 nets.

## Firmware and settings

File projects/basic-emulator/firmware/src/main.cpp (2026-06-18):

#include <Arduino.h>
#include <led/led_controller.h>
#include "config/config.h"
#include "lego/toypad.h"
#include "log/logger.h"
#include "RP2040Support.h"
#include "web/captive_portal.h"
#include "web/server.h"

CaptivePortal* initializationPortal = nullptr;
LegoServer* webServer = nullptr;
Toypad playPad;

PlaypadLEDController<4> padLEDs(&playPad, {3, 1, 3});

void create_captive_portal() {
    logger.blinkStatus(5, 1000);
    playPad.getPad(PadLocation::CENTER)->setColor(PadColor::Red());

    log_dbg("[create_captive_portal] Creating captive portal...");
    initializationPortal = new CaptivePortal("captive", NULL);
    log_dbg("[create_captive_portal] Waiting for initialization...");
}

void setup() {
#ifdef PICO_RP2040
    // Enable the double reset detector,
    // So that if the user double-taps the reset button, it'll boot into the UF2 bootloader for easy
    // flashing
    rp2040.enableDoubleResetBootloader();
#endif

    randomSeed(analogRead(A1));

    log_init();
    config.init();

    playPad.begin();
    padLEDs.begin();

    if (config.getBool("initialized", false)) {
        log_dbg("[setup] Device already initialized, skipping captive portal...");
        logger.blinkStatus(2, 100);

        if (playPad.platform() == ToypadPlatform::PS3) {
            playPad.getPad(PadLocation::CENTER)->setFade(PadColor::Blue(), 50, 2);
        } else {
            playPad.getPad(PadLocation::CENTER)->setFade(PadColor::Green(), 50, 2);
        }

        return;
    }

    log_dbg("[setup] Device not initialized, creating captive portal...");
    create_captive_portal();
}

void loop() {
    // Updates the current USB state (i.e. sending events/etc/etc)
    playPad.update();
    padLEDs.update();

    if (initializationPortal != nullptr) {
        // For the sake of seeing if the portal is initialized, just blink the LED on/off while we
        // check for DNS requests/etc.
        initializationPortal->loop();

        // Check if the credentials have been saved, if so, it's time to initialize our connection
        // to the WiFi instance.
        if (initializationPortal->credentialsSaved) {
            delete initializationPortal;
            initializationPortal = nullptr;
        }

        return;
    }

    if (webServer == nullptr) {
        log_dbg("[loop] Initializing Playpad Server...");

        const char* ssid = config.getString("ssid", "");
        const char* pass = config.getString("password", "");

        webServer = new LegoServer(ssid, pass, &playPad);

        free((void*)ssid);
        free((void*)pass);

        if (!webServer->success) {
            delete webServer;
            webServer = nullptr;

            create_captive_portal();
            return;
        }

        assert(webServer->success);
    }

    if (webServer != nullptr) {
        webServer->loop();
    }

#ifdef TINYUSB_NEED_POLLING_TASK
    // Manual call tud_task since it isn't called by Core's background
    TinyUSBDevice.task();
#endif
}

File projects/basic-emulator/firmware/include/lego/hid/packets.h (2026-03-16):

#include "lego/hid/packet.h"
#include "lego/hid/pad.h"
#include "lego/tag.h"

/**
 * @brief A SEED packet is used to seed the PRNG, as well as a part of the authentication process.
 * The main payload (first 8 bytes) of the packet are encrypted via TEA.
 *
 */
struct SeedPacket : CommandPacket {
    static constexpr uint8_t PAYLOAD_SIZE = 8;

    // Parsed/decrypted contents of a SEED command payload
    struct SeedStatus {
        uint32_t seed;  // read as LE - burtle.init(seed)
        uint32_t conf;  // read as BE - echoed back in response
    };

    /// @brief Parses and decrypts an incoming SEED command from the device.
    /// @param packet Raw CommandPacket received from the device
    /// @param crypto TEA instance with the shared key already set
    /// @return Decrypted SeedStatus, or {0,0} on failure
    static SeedStatus fromCommand(const CommandPacket& packet, TEA* crypto) {
        const uint8_t* decrypted = BasePacket::decryptPayload(&packet, crypto);
        if (!decrypted) {
            return {0, 0};
        }

        const uint32_t seed = Reader::readUInt32LE(decrypted, 0x00);
        const uint32_t conf = Reader::readUInt32BE(decrypted, 0x04);

        free((void*)decrypted);
        return {seed, conf};
    }

    /// @brief Builds an encrypted SEED response to send back to the device.
    ///        Response payload: [conf_u32be][0x00 x4] encrypted
    /// @param cid    CID mirrored from the incoming command
    /// @param status SeedStatus from fromCommand()
    /// @param crypto TEA instance with the shared key already set
    /// @return ResponsePacket
    static ResponsePacket fromStatus(uint8_t cid, const SeedStatus& status, TEA* crypto) {
        uint8_t payload[PAYLOAD_SIZE]{};
        Reader::writeUInt32BE(payload, 0x00, status.conf);  // conf as BE at offset 0

        // Encrypt the full 8-byte block before building the packet
        uint8_t encrypted[PAYLOAD_SIZE]{};
        if (!crypto->encrypt(payload, encrypted)) {
            return {};
        }

        ResponsePacket pkt = ResponsePacket::build(cid, encrypted, PAYLOAD_SIZE);
        return pkt;
    }
};

/**
 * @brief A CHALLENGE packet is used to help authenticate that this pad is a "legal" playpad.
 * The packet payload comes encrypted through TEA, & needs to be decrypted. Afterwards, it includes
 * a uint32 `conf` key. The seeded RNG will generate a random number, and send it back as a
 * response. This proves both the PRNG is implemented correctly, as well as TEA.
 * So it *obviously* has to be an official playpad...
 *
 */
struct ChallengePacket : CommandPacket {
    static constexpr uint8_t PAYLOAD_SIZE = 8;

    // Parsed/decrypted contents of a CHALLENGE command payload
    struct ChallengeStatus {
        uint32_t conf;  // read as BE - echoed back in response
    };

    /// @brief Parses and decrypts an incoming SEED command from the device.
    /// @param packet Raw CommandPacket received from the device
    /// @param crypto TEA instance with the shared key already set
    /// @return Decrypted ChallengeStatus, or {0xFFFFFFFF} on failure
    static ChallengeStatus fromCommand(const CommandPacket& packet, TEA* crypto) {
        const uint8_t* decrypted = BasePacket::decryptPayload(&packet, crypto);
        if (!decrypted) {
            return {0xFFFFFFFF};
        }

        const uint32_t conf = Reader::readUInt32BE(decrypted, 0x00);

        free((void*)decrypted);
        return {conf};
    }

    /// @brief Builds an encrypted SEED response to send back to the device.
    ///        Response payload: [conf_u32be][0x00 x4] encrypted
    /// @param cid    CID mirrored from the incoming command
    /// @param rand   A random PRNG number generated from Burtle
    /// @param status ChallengeStatus from fromCommand()
    /// @param crypto TEA instance with the shared key already set
    /// @return ResponsePacket
    static ResponsePacket fromStatus(uint8_t cid,
                                     uint32_t rand,
                                     const ChallengeStatus& status,
                                     TEA* crypto) {
        uint8_t payload[PAYLOAD_SIZE]{};
        Reader::writeUInt32LE(payload, 0x00, rand);
        Reader::writeUInt32BE(payload, 0x04, status.conf);

        // Encrypt the full 8-byte block before building the packet
        uint8_t encrypted[PAYLOAD_SIZE]{};
        if (!crypto->encrypt(payload, encrypted)) {
            return {};
        }

        ResponsePacket pkt = ResponsePacket::build(cid, encrypted, PAYLOAD_SIZE);
        return pkt;
    }
};

/**
 * @brief A COLOR packet changes the color of a specific playpad
 *
 */
struct ColorPacket : CommandPacket {
    // Parsed/decrypted contents of a COLOR command payload
    struct ColorStatus {
        PadLocation padLocation;
        PadColor padColor;
    };

    /// @brief Parses an incoming COLOR command from the device.
    /// @param packet Raw CommandPacket received from the device
    /// @return A parsed COLOR command
    static ColorStatus fromCommand(const CommandPacket& packet) {
        const uint8_t* decrypted = packet.payload();

        const PadLocation padIndex = static_cast<PadLocation>(decrypted[0]);
        const PadColor padColor = PadColor::fromBuffer(&decrypted[1]);

        return {padIndex, padColor};
    }
};

/**
 * @brief A COLAL packet lets you change the colors of all of the specific playpads in a single
 * packet.
 *
 */
struct ColorAllPacket : CommandPacket {
    // Parsed/decrypted contents of a COLORALL command payload
    struct ColorStatus {
        PadColor centerColor;
        PadColor leftColor;
        PadColor rightColor;
    };

    /// @brief Parses an incoming COLORALL command from the device.
    /// @param packet Raw CommandPacket received from the device
    /// @return A parsed COLOR command
    static ColorStatus fromCommand(const CommandPacket& packet) {
        const uint8_t* decrypted = packet.payload();

        ColorStatus result{};
        for (int i = 0; i < 3; i++) {
            const int offset = i * 4;
            const PadLocation loc = static_cast<PadLocation>(decrypted[offset]);
            const PadColor color = PadColor::fromBuffer(&decrypted[offset + 1]);

            switch (loc) {
                case PadLocation::CENTER:
                    result.centerColor = color;
                    break;
                case PadLocation::LEFT:
                    result.leftColor = color;
                    break;
                case PadLocation::RIGHT:
                    result.rightColor = color;
                    break;
                default:
                    break;
            }
        }

        return result;
    }
};
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

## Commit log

2025-08-14 Initial basic-rgb commit
    [PS3PCB.kicad_sch, basic-rgb.kicad_pcb, basic-rgb.kicad_sch]
2026-03-06 Very basic basic-emulator implementation + PCB
    [basic-emulator.kicad_pcb, basic-emulator.kicad_sch]
2026-03-12 Add websockets support for colors + extra packets
    [basic-emulator.kicad_pcb, basic-emulator.kicad_sch]
2026-03-13 Restructure Repository
    [PS3PCB.kicad_pcb, PS3PCB.kicad_sch, basic-emulator.kicad_pcb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]
2026-03-16 Extra bug fixes, more memory allocation fixes, fix packet parsing
    [main.cpp, packets.h, pad.h]
2026-05-07 feat: add xbox 360 support + extra emulator tweaks
    Adds Xbox 360 Support into the RGB-Controller project, tweaks fronend UI design for emulator, as well as adding a case for the RGB-Controller + Redesigning the PCB for RGB-controller
    BREAKING CHANGE:
    [BottomShell.ipt, BottomShell.stl, TopShell.ipt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]
2026-06-18 feat(usb): add x360 usbdsec authentication
    Supports modded Xbox 360s with the usbdsec patch applied
    [Part16.ipt, board-view.step, bottom-case.stl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]
2026-07-18 fix(emulator): update to my fork of tinyusb
    This lets you easily download/setup the repo. Since I updated the fork, I needed to tweak the vendor logic. Next up is proper XSM3 support
    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
    [logger.cpp, x360_usb.cpp]
